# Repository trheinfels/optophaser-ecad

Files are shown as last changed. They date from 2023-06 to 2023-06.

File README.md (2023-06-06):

# Optophaser Guitar Pedal - ECAD

This repository contains the ECAD files for an eight stage optophaser guitar effect pedal designed in KiCad.

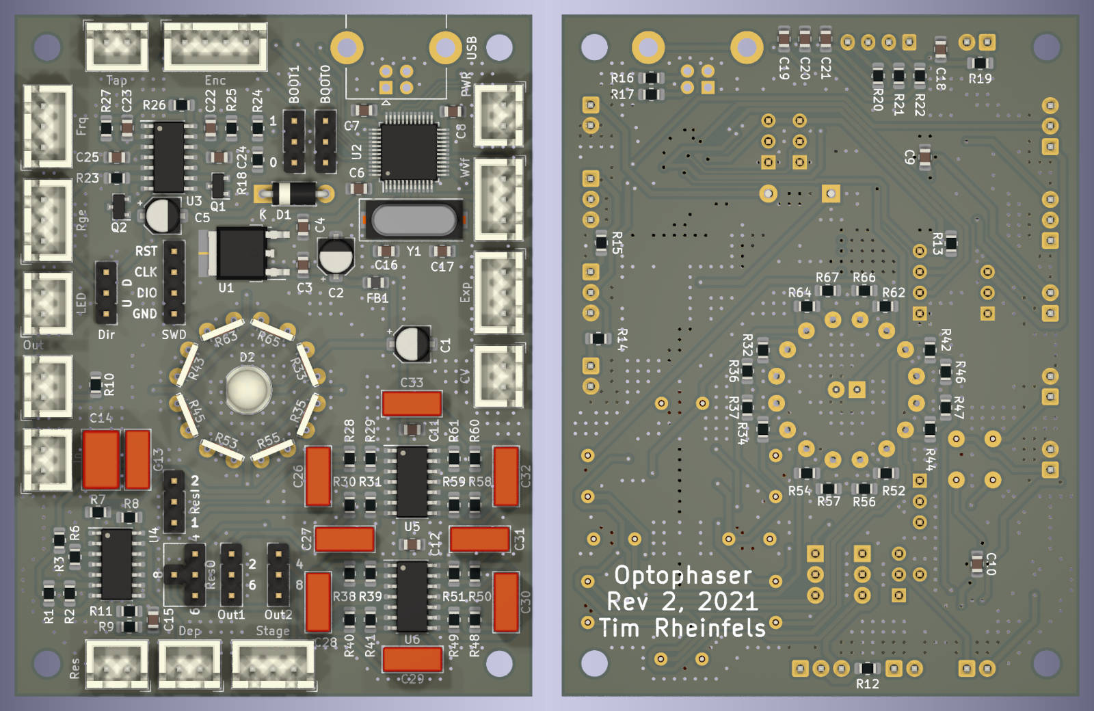
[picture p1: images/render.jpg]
Render view of the PCB


# Features

The phaser is based around well-known analog circuitry. What sets it apart from commercially available units is the large number of controls, the configurability (there are multiple combinations of voices), and the digital synthesis of the LFO signal. Both are detailed in the following sections.

## Controls

Beside a switch which allows for selecting the number of phaser stages and a tap tempo button, the controls comprise five potentiometers:

- Waveform: Blends between different LFO wave forms
- Frequency: LFO frequency
- Range: LFO amplitude (i.e., the frequency range the phaser spans)
- Depth: Gain for the mix (i.e., the amount of phasing effect)
- Resonance: Feedback gain (makes the phaser sound more *nasty*)

## Configurability

While not intended to be exposed to the case, there are multiple configuration options which can be selected via jumpers:

- Dir: Direction in which the LFO modulates the comb filter frequencies
- Out1: First tap of the phaser stage switch. Uses either the signal after the second or the sixth phasing stage
- Out2: Second tap of the phaser stage switch. Uses either the signal after the fourth or the eigth phasing stage
- ResO: Selects the origin of the resonance feedback signal. Either after the fourth, sixth, or eigth stage
- ResI: Selects the destination of the resonance feedback signal. Insert it either into the first or second phasing stage

## MCU-based LFO

Instead of an analog circuitry, this phaser unit uses an STM32 microcontroller for generating low-frequency oscillator signal which modulates the comb filter frequencies. This allows for implementing unusual features such as

- Generating arbitrary waveforms and blending them on the fly
- Tap tempo
- Expression pedal input (either resistive or via control voltage)

For the sake of usability, the MCU can be connected via USB. This allows for firmware updates and can potentially be used to upload arbitrary waveforms to the phaser.

## License

The ECAD files are licensed under CC-BY-SA, see [COPYING](COPYING).

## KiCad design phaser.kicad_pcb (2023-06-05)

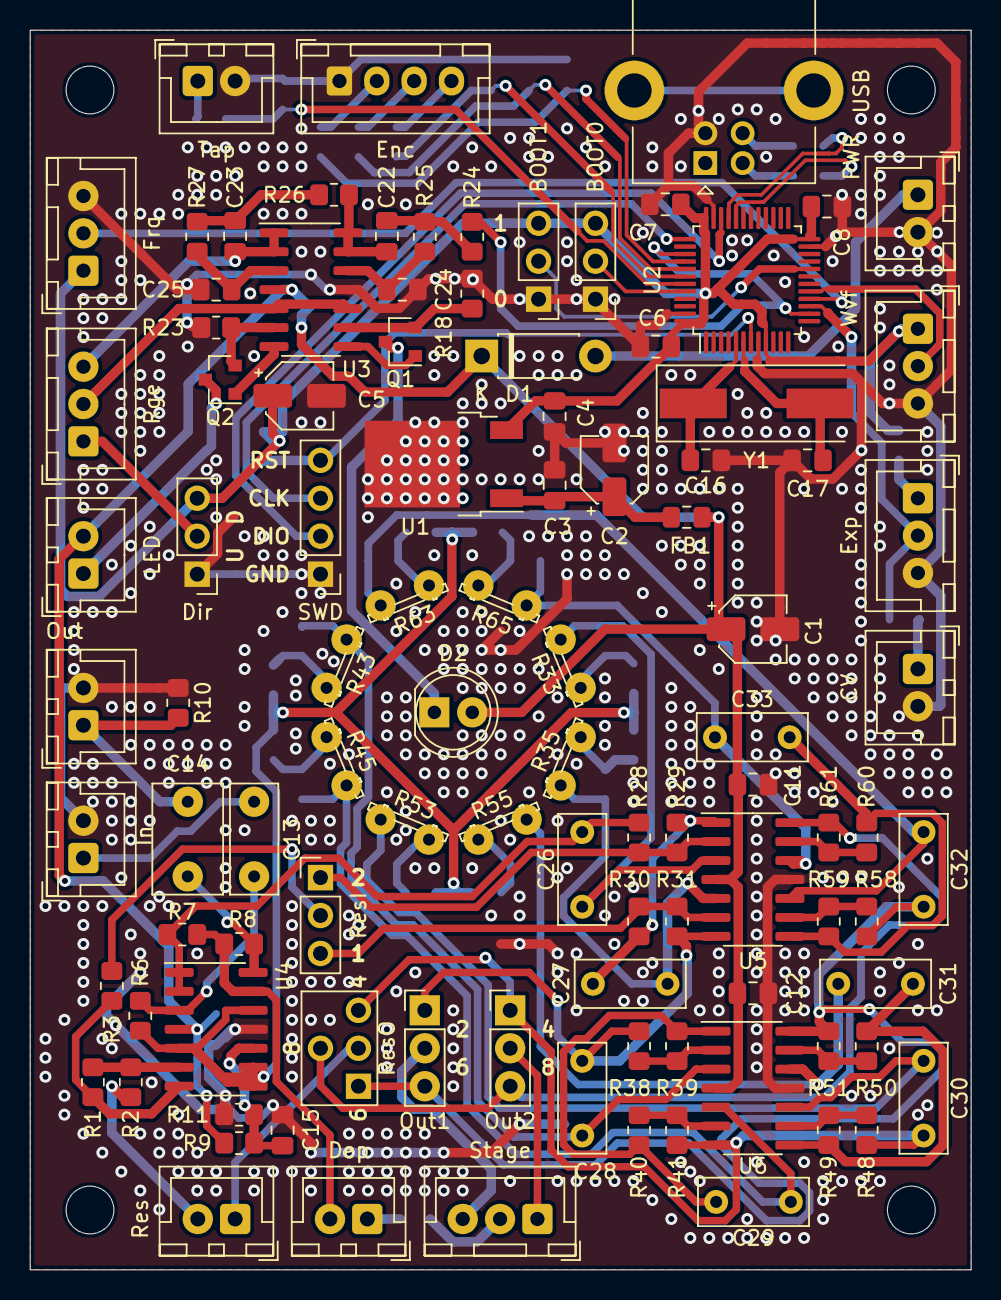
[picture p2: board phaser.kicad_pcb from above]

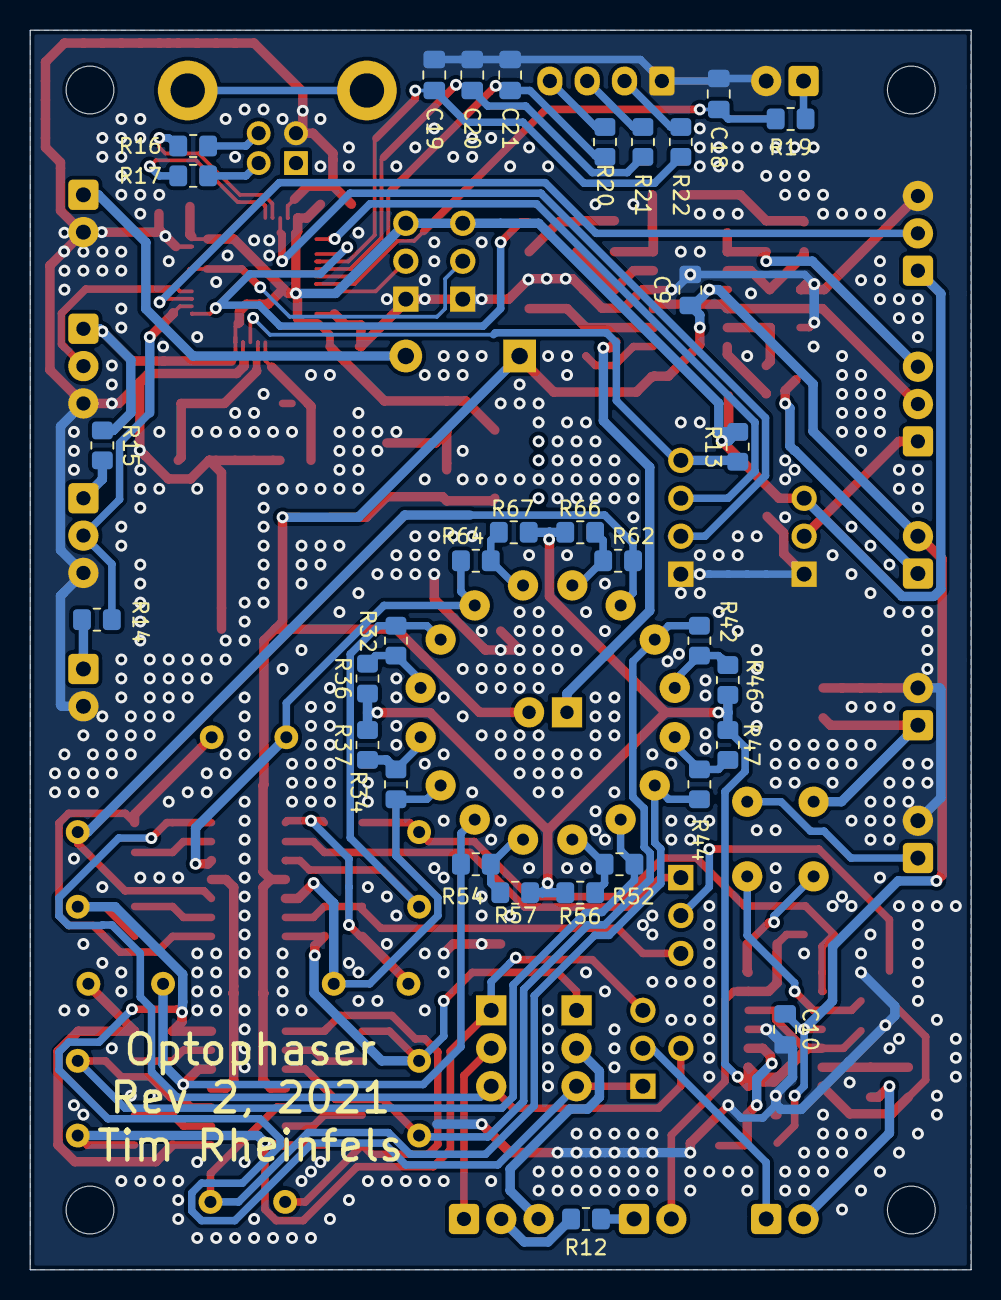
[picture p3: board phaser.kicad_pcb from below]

Board: 2 copper layers, 63.0 x 83.0 mm, 137 parts (32 on the bottom side), 93 nets.

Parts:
C1, C2, C5: 10u; CP_Elec_4x5.4
C3, C4, C6, C7, C8, C9, C10, C11, C12, C18, C19, C20, C21: 100n; C_0805_2012Metric_Pad1.18x1.45mm_HandSolder
C13, C26, C27, C28, C29, C30, C31, C32, C33: 22n; C_Rect_L7.2mm_W3.0mm_P5.00mm_FKS2_FKP2_MKS2_MKP2
C14: 68n; C_Rect_L7.2mm_W4.5mm_P5.00mm_FKS2_FKP2_MKS2_MKP2
C15: 22n; C_0805_2012Metric_Pad1.18x1.45mm_HandSolder
C16, C17: 15p; C_0805_2012Metric_Pad1.18x1.45mm_HandSolder
C22, C23, C24, C25: 15n; C_0805_2012Metric_Pad1.18x1.45mm_HandSolder
D1: SB120; D_DO-41_SOD81_P7.62mm_Horizontal
D2: LED; LED_D5.0mm_Clear
FB1: Ferrite_Bead; L_0805_2012Metric_Pad1.15x1.40mm_HandSolder
H1, H2, H3, H4: MountingHole_3.2mm_M3
J1: Res; JST_XH_B2B-XH-A_1x02_P2.50mm_Vertical
J2: PWR; JST_XH_B2B-XH-A_1x02_P2.50mm_Vertical
J3: In; JST_XH_B2B-XH-A_1x02_P2.50mm_Vertical
J4: Out; JST_XH_B2B-XH-A_1x02_P2.50mm_Vertical
J5: Out1; PinHeader_1x03_P2.54mm_Vertical
J6: Out2; PinHeader_1x03_P2.54mm_Vertical
J7: Stage; JST_XH_B3B-XH-A_1x03_P2.50mm_Vertical
J8: Dep; JST_XH_B2B-XH-A_1x02_P2.50mm_Vertical
J9: CV; JST_XH_B2B-XH-A_1x02_P2.50mm_Vertical
J10: SWD; PinHeader_1x04_P2.54mm_Vertical
J11: Dir; PinHeader_1x03_P2.54mm_Vertical
J12: Exp; JST_XH_B3B-XH-A_1x03_P2.50mm_Vertical
J13: Rge; JST_XH_B3B-XH-A_1x03_P2.50mm_Vertical
J14: USB; USB_B_Lumberg_2411_02_Horizontal
J15: Frq; JST_XH_B3B-XH-A_1x03_P2.50mm_Vertical
J16: Wvf; JST_XH_B3B-XH-A_1x03_P2.50mm_Vertical
J17: Tap; JST_XH_B2B-XH-A_1x02_P2.50mm_Vertical
J18: BOOT0; PinHeader_1x03_P2.54mm_Vertical
J19: LED; JST_XH_B2B-XH-A_1x02_P2.50mm_Vertical
J20: BOOT1; PinHeader_1x03_P2.54mm_Vertical
J21: Enc; JST_XH_B4B-XH-A_1x04_P2.50mm_Vertical
J22: ResI; PinHeader_1x03_P2.54mm_Vertical
JP1: ResO; Sel3
Q1, Q2: BC846; SOT-23
R1: 1k; R_0805_2012Metric_Pad1.20x1.40mm_HandSolder
R2: 2k; R_0805_2012Metric_Pad1.20x1.40mm_HandSolder
R3, R7, R8, R9, R11, R12, R13, R19, R20, R21, R22, R28, R29, R30, R31, R36, R37, R38, R39, R40, R41, R46, R47, R48, R49, R50, R51, R56, R57, R58, R59, R60, R61, R66, R67: 10k; R_0805_2012Metric_Pad1.20x1.40mm_HandSolder
R6: 470k; R_0805_2012Metric_Pad1.20x1.40mm_HandSolder
R10: 150k; R_0805_2012Metric_Pad1.20x1.40mm_HandSolder
R14, R15: 100; R_0805_2012Metric_Pad1.20x1.40mm_HandSolder
R16, R17: 22; R_0805_2012Metric_Pad1.20x1.40mm_HandSolder
R18, R23: 165; R_0805_2012Metric_Pad1.20x1.40mm_HandSolder
R24, R25, R26, R27, R32, R34, R42, R44, R52, R54, R62, R64: 100k; R_0805_2012Metric_Pad1.20x1.40mm_HandSolder
R33, R35, R43, R45, R53, R55, R63, R65: 2k-230k; R_LDR_5.2x5.2mm_P3.5mm_Horizontal
U1: LF33; TO-252-2
U2: STM32L151CBTxA; LQFP-48_7x7mm_P0.5mm
U3: LM324; SOIC-14_3.9x8.7mm_P1.27mm
U4, U5, U6: TL074; SOIC-14_3.9x8.7mm_P1.27mm
Y1: 16 MHz; Crystal_SMD_HC49-SD

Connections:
+3V3: C4.1, C5.1, C6.2, C7.2, C8.2, J11.3, J15.1, J16.1, J18.3, J20.3, R13.2, R15.1, U1.3, U2.9, U2.24, U2.36, U2.48
+9V: C1.1, C9.1, C10.1, C11.1, C12.1, D1.1, D2.2, FB1.2, J19.2, R9.1, U3.4, U4.4, U5.4, U6.4
/low_pass/y: C23.1, J13.3, U3.1, U3.2
/stage_12/res1: J22.1, R28.1, R29.2, U5.2
/stage_12/res2: J22.3, R30.1, R31.2, U5.6
/stage_12/u: C26.2, R7.2, R28.2, U4.1, U4.2
/stage_34/u: C28.2, J5.1, R31.1, R38.2, U5.7
/stage_56/u: C30.2, J6.1, JP1.3, R41.1, R48.2, U6.7
/stage_78/u: C32.2, J5.3, JP1.1, R51.1, R58.2, U6.14
/stage_78/y: J6.3, JP1.2, R61.1, U5.14
BOOT0: J18.2, U2.44
BOOT1: J20.2, U2.20
CV: J12.2, R14.2, U2.15
D+: R16.2, U2.33
D-: R17.2, U2.32
DAC: R24.2, U2.14, U2.39
ENC_A: C19.1, R22.1, U2.40
ENC_B: C20.1, R21.1, U2.41
ENC_S: C21.1, R20.1, U2.42
Frq: J15.2, U2.16
GND: C1.2, C2.2, C3.2, C4.2, C5.2, C6.1, C7.1, C8.1, C9.2, C10.2, C11.2, C12.2, C15.2, C16.1, C17.1, C18.2, C19.2, C20.2, C21.2, C24.1, C25.1, J2.2, J3.2, J4.2, J9.2, J10.1, J11.1, J12.3, J14.4, J15.3, J16.3, J17.2, J18.1, J20.1, J21.1, R10.1, R11.2, R18.1, R23.1, U1.2, U2.8, U2.23, U2.35, U2.47, U3.11, U4.11, U5.11, U6.11
GNDA: R6.1, R36.2, R37.2, R46.2, R47.2, R56.2, R57.2, R66.2, R67.2, U4.5, U4.8, U4.9, U4.12
NRST: J10.4, R13.1, U2.7
unnamed: C2.1, C3.1, FB1.1, U1.1
unnamed: C13.1, R6.2, U4.3
unnamed: C13.2, J3.1
unnamed: C14.1, J4.1, R10.2
unnamed: C14.2, R8.1, U4.14
unnamed: C15.1, R9.2, R11.1, U4.10
unnamed: C16.2, U2.5, Y1.1
unnamed: C17.2, U2.6, Y1.2
unnamed: C22.1, R26.2, U3.13, U3.14
unnamed: C22.2, R24.1, R25.2
unnamed: C23.2, R26.1, R27.2
unnamed: C24.2, R25.1, U3.12
unnamed: C25.2, R27.1, U3.3
unnamed: C26.1, R32.1, R33.2, U5.3
unnamed: C27.1, R34.1, R35.1, U5.5
unnamed: C27.2, R29.1, R30.2, U5.1
unnamed: C28.1, R42.1, R43.1, U6.3
unnamed: C29.1, R44.1, R45.2, U6.5
unnamed: C29.2, R39.1, R40.2, U6.1
unnamed: C30.1, R52.1, R53.1, U6.10
unnamed: C31.1, R54.1, R55.2, U6.12
unnamed: C31.2, R49.1, R50.2, U6.8
unnamed: C32.1, R62.1, R63.2, U5.10
unnamed: C33.1, R64.1, R65.1, U5.12
unnamed: C33.2, R59.1, R60.2, U5.8
unnamed: D1.2, J2.1
unnamed: D2.1, Q1.3
unnamed: J1.1, JP1.4
unnamed: J1.2, R2.1
unnamed: J5.2, J7.3
unnamed: J6.2, J7.1
unnamed: J7.2, R12.2
unnamed: J8.1, R12.1
unnamed: J8.2, R7.1, R8.2, U4.13
unnamed: J9.1, R14.1
unnamed: J11.2, J13.1
unnamed: J12.1, R15.2
unnamed: J13.2, U3.5, U3.10
unnamed: J14.2, R17.1
unnamed: J14.3, R16.1
unnamed: J17.1, R19.2
unnamed: J19.1, Q2.3
unnamed: J21.2, R22.2
unnamed: J21.3, R21.2
unnamed: J21.4, R20.2
unnamed: J22.2, R3.2
unnamed: Q1.1, U3.8
unnamed: Q1.2, R18.2, U3.9
unnamed: Q2.1, U3.7
unnamed: Q2.2, R23.2, U3.6
unnamed: R1.1, R2.2, U4.6
unnamed: R1.2, R3.1, U4.7
unnamed: R32.2, R33.1, R36.1
unnamed: R34.2, R35.2, R37.1
unnamed: R38.1, R39.2, U6.2
unnamed: R40.1, R41.2, U6.6
unnamed: R42.2, R43.2, R46.1
unnamed: R44.2, R45.1, R47.1
unnamed: R48.1, R49.2, U6.9
unnamed: R50.1, R51.2, U6.13
unnamed: R52.2, R53.2, R56.1
unnamed: R54.2, R55.1, R57.1
unnamed: R58.1, R59.2, U5.9
unnamed: R60.1, R61.2, U5.13
unnamed: R62.2, R63.1, R66.1
unnamed: R64.2, R65.2, R67.1
SWCLK: J10.3, U2.37
SWDIO: J10.2, U2.34
Tap: C18.1, R19.1, U2.43
Wvf: J16.2, U2.17

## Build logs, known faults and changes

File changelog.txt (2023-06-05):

Revision 2:
- ATMega32U2 -> STM32L151
- Add DAC output as alternative for PWM
- Solder Bridges -> Jumpers
- Pin Headers -> JST XH
- Rename U2 <-> U3
- TL074 -> LM324 for LED driver
- 6th -> 4th order low-pass
- Additional LED driver
- Fix mixed up phase shifter opamp inputs
- Buffer input signal to avoid attenuation at the output mixer
- Move resistor in resonance path
- Add resonance selector
- Set resonance stage gain to <= 1
- Set component values to a center frequency range of around 90-600 Hz
- Add capacitor to voltage divider for virtual ground
- Add ferrite bead between 9V rail and uc voltage regulator
- Replace USB header with dedicated type B jack
- Move PCB label from copper to silk screen
- Add connections for a rotary encoder
- Add via stitching

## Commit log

2023-06-05 Revision 1
    [low_pass.sch, phaser.kicad_pcb, phaser.sch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]
2023-06-05 Revision 2
    See changelog.txt
    [low_pass.sch, phaser.kicad_pcb, phaser.sch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]
